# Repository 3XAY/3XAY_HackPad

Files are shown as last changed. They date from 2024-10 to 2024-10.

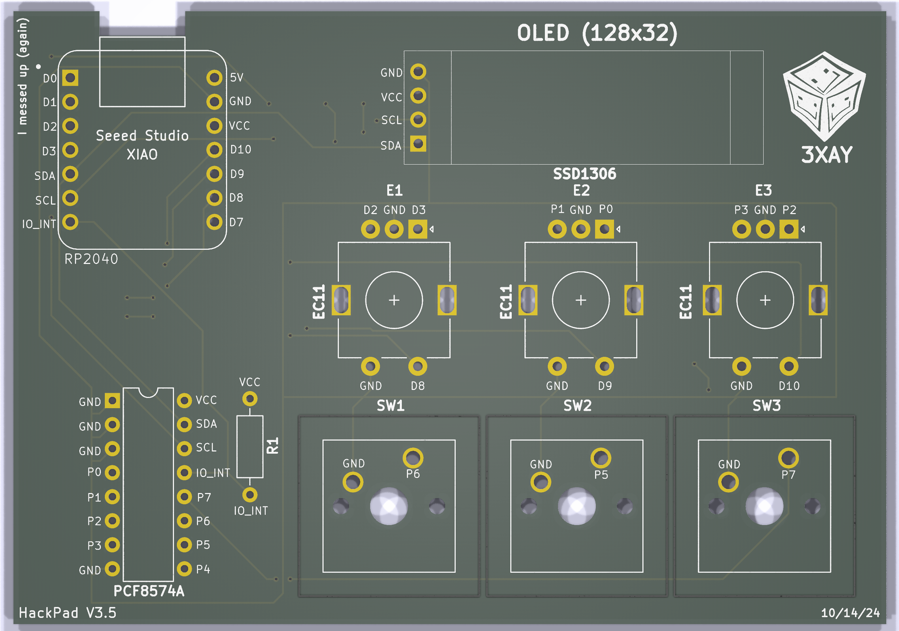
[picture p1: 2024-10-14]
Images/V3.5/PCB3DViewFront.png

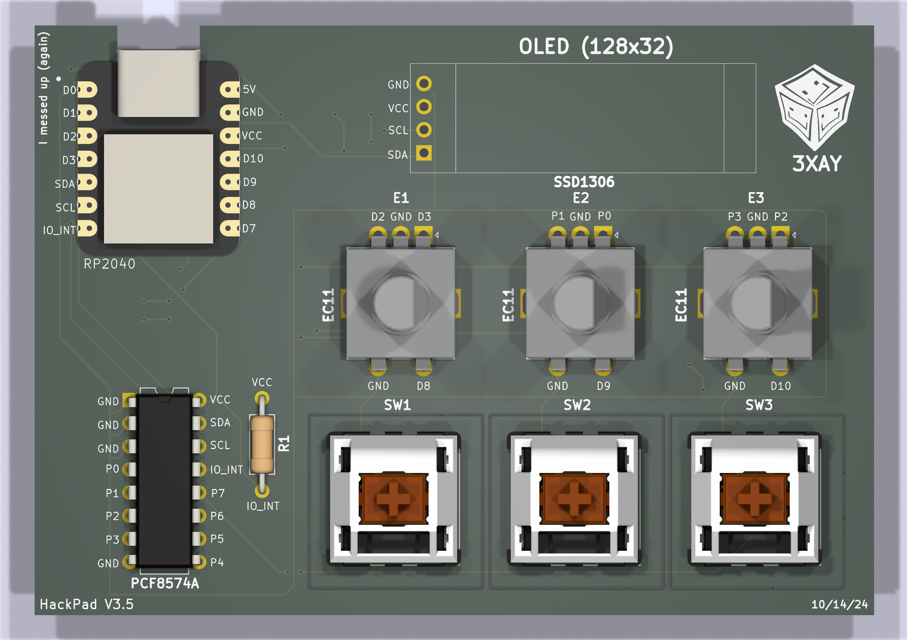
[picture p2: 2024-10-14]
Images/V3.5/PCB3DViewFrontWithModels.png

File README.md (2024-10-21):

# HackPad

This is currently a work in progress. **THIS MEANS NOTHING IS TESTED, DO NOT ATTEMPT TO USE THIS AS A GUIDE** (as of now)
[here's the submission link if you want it](https://github.com/hackclub/hackpad/pull/187)

This is my submission for Hack Club's HackPad YSWS (You ship we ship).
My progress will be throughouly documented here.

## Images
These are screenshots from the development process with each design iteration. (For the PCB / Case, code can be reviewed via the version history)

## KiCad
These are the KiCad files.

## Blender
Any Blender files made will be stored here, these are either sketches, renders, or CAD files
- Here's the tool I used to export from KiCad to Blender: https://github.com/30350n/pcb2blender

## Firmware
All of the firmware is written in Circuitpython (currently untested)

## YouTube Shorts Recaps
https://youtube.com/playlist?list=PL8pZ9v0F1Ks2gfHrP7J-pUTj4NAnL8gHc&si=MliIfDuidp5TVAae

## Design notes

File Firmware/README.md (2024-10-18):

The .UF2 file is meant to be flashed to the MCU (RP2040 in this case), allowing it to work with CircuitPython

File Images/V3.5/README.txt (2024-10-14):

The PCB schematic is the same as V3, so are the keymaps and the idea.

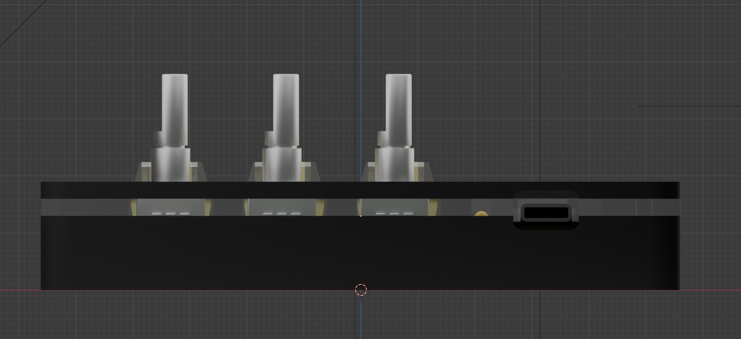
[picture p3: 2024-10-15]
Images/V3.5/unfinishedCaseUSBPort.png

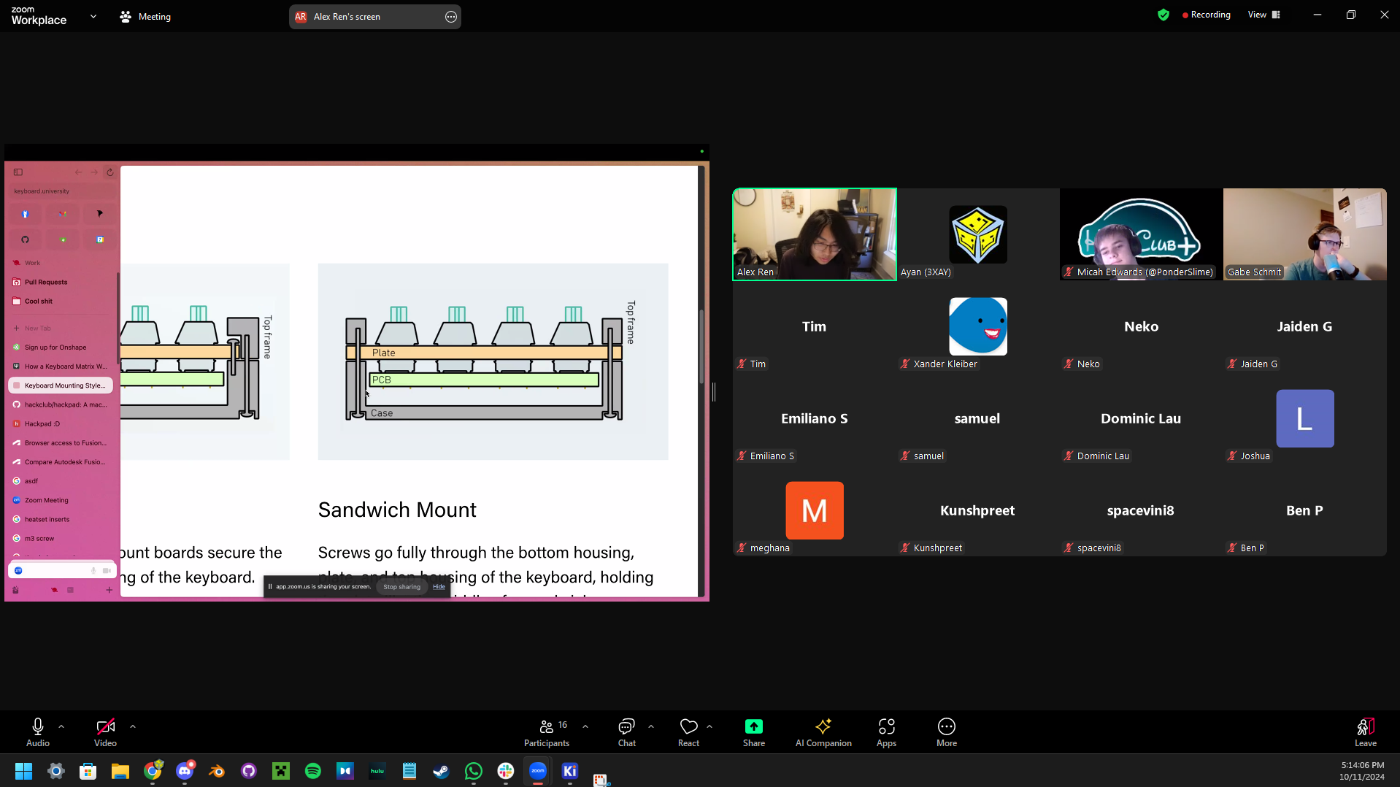
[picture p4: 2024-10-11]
Images/General/10-11-24 - Workshop.png

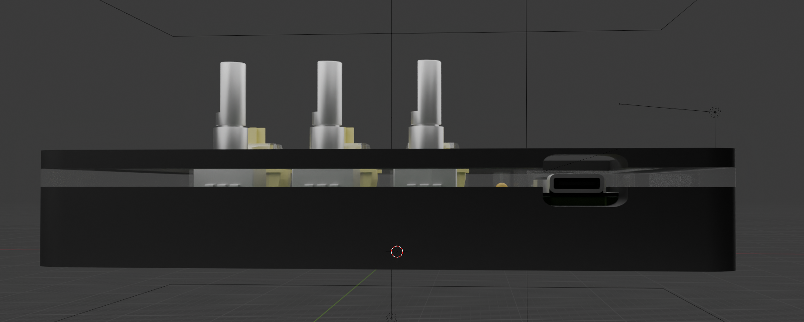
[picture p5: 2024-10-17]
Images/V3.5/finishedCaseUSBPort.png

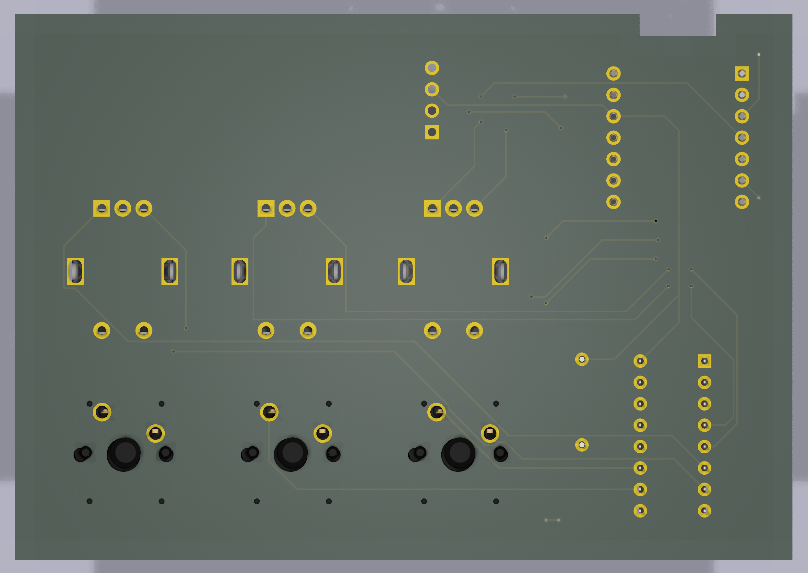
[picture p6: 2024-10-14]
Images/V3.5/PCB3DViewBackWithModels.png

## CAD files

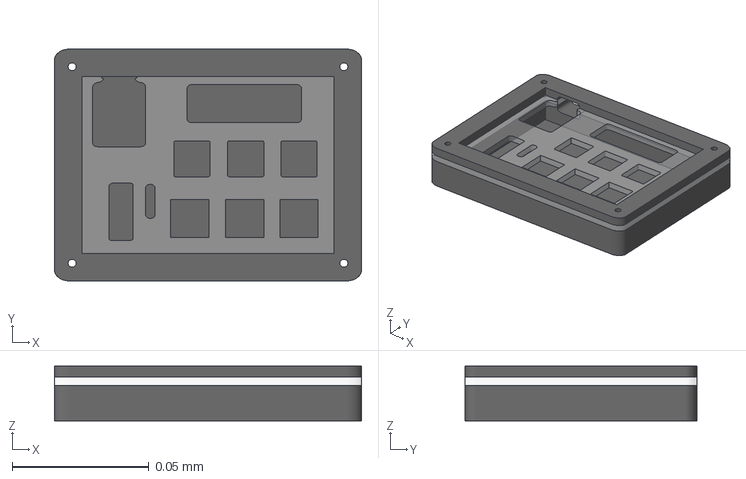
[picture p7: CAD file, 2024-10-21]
Blender/CAD Files/3MF/fullHackPad.3mf
0.112 x 0.0848 x 0.02 mm

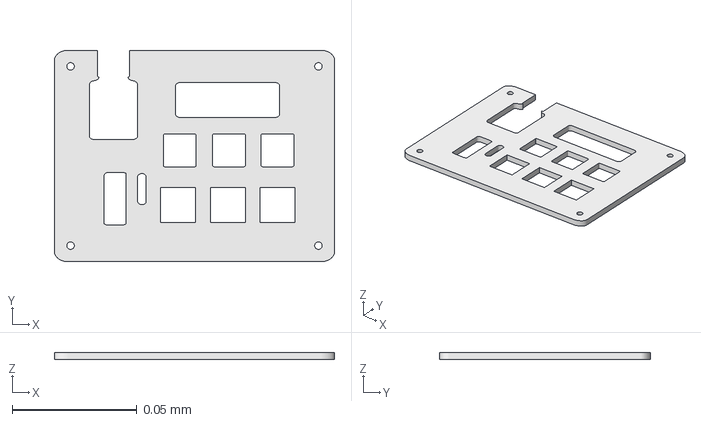
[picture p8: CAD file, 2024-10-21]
Blender/CAD Files/3MF/switchPlate.3mf
0.112 x 0.0848 x 0.003 mm

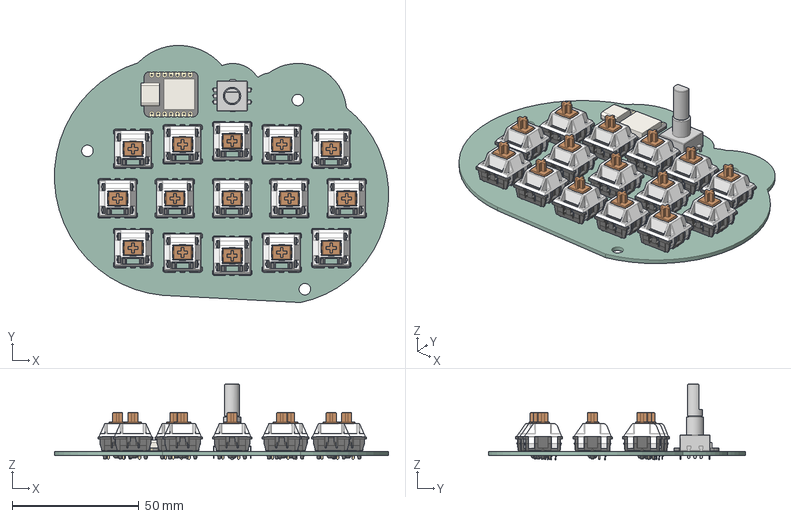
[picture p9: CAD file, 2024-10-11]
KiCad/footprints/models/models/frogpad.step
131.9 x 101.5 x 29.8 mm
SW_Cherry_MX_PCB x 15
Seeeduino Xiao v2
(Unsaved)
my_hackpad_PCB

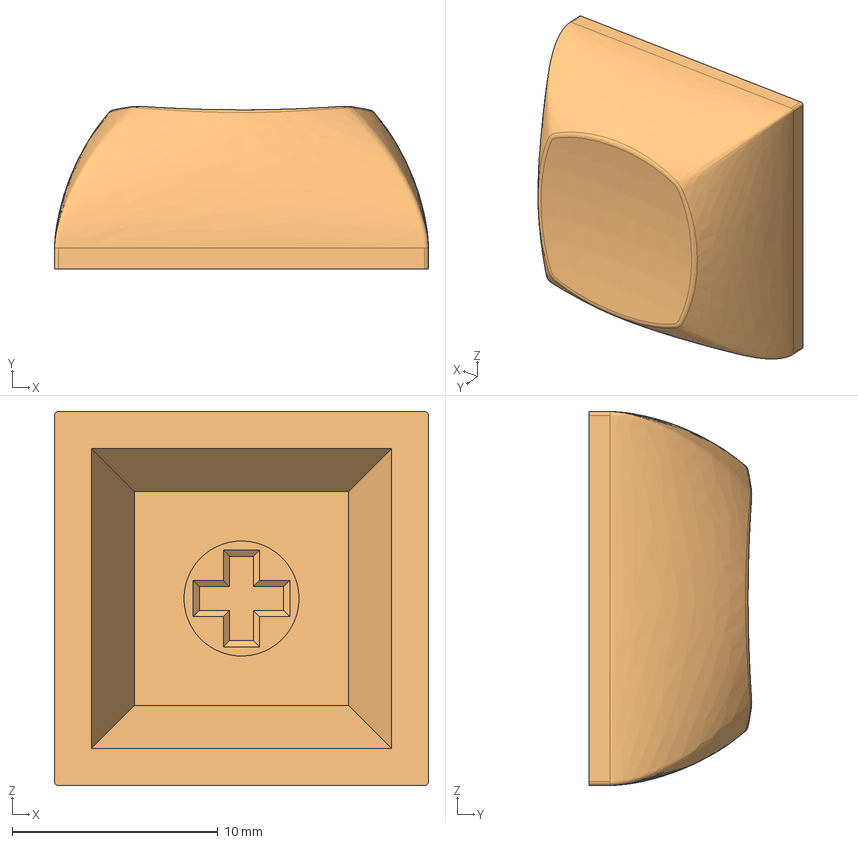
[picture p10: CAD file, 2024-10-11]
KiCad/footprints/models/models/DSA 1u.step
18.2 x 7.91 x 18.2 mm

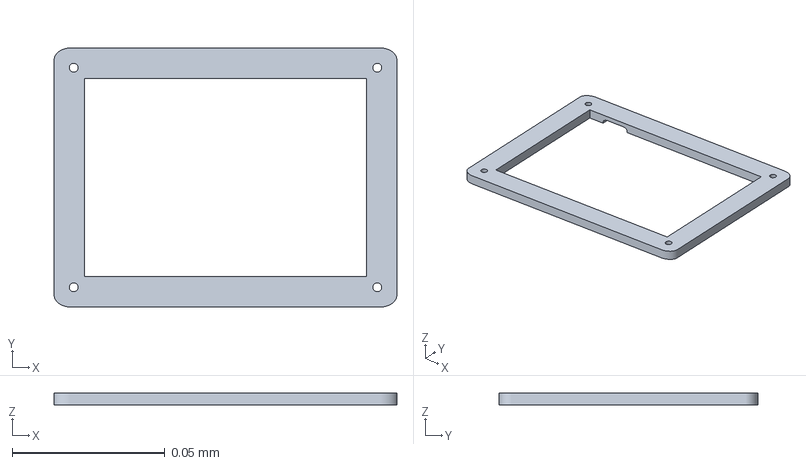
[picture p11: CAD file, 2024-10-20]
Blender/CAD Files/3MF/topPlate.3mf
0.112 x 0.0848 x 0.004 mm

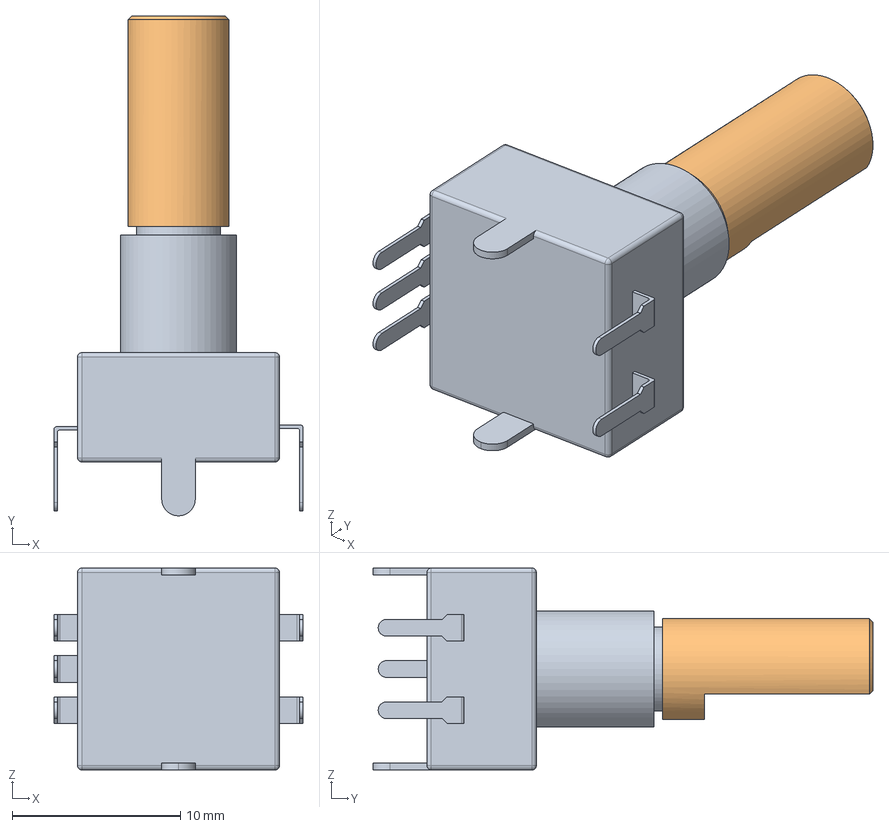
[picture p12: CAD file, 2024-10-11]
KiCad/footprints/models/models/Rotary Encoder.step
14.8 x 29.7 x 12.0 mm

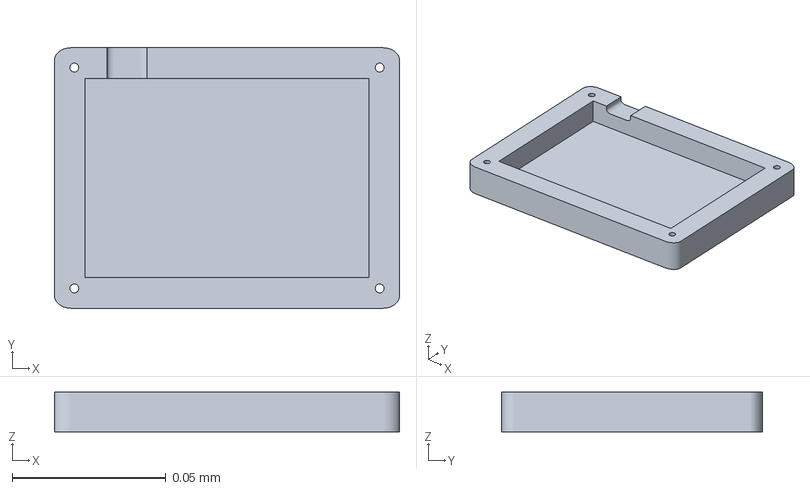
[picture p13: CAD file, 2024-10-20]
Blender/CAD Files/3MF/bottomCase.3mf
0.112 x 0.0848 x 0.013 mm

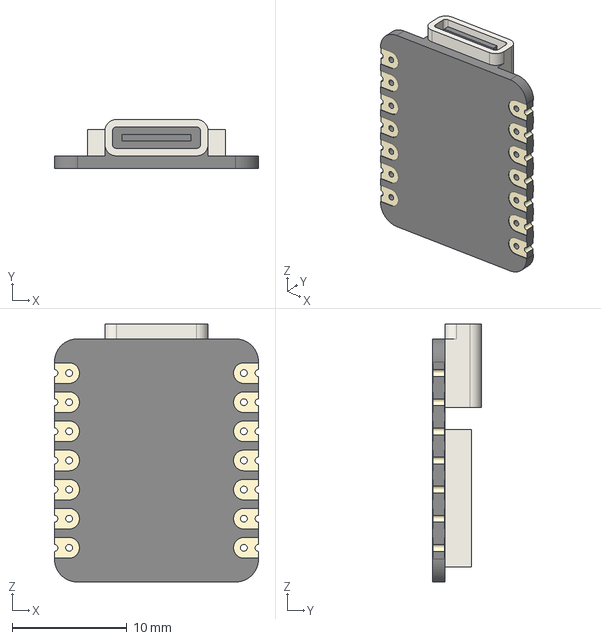
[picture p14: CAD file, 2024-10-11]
KiCad/footprints/models/models/Seeeduino_Xiao.step
17.8 x 4.27 x 22.5 mm

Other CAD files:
Blender/hackpadCAD.blend
Blender/hackpadIdea_V3.blend
hackpadIdea.blend

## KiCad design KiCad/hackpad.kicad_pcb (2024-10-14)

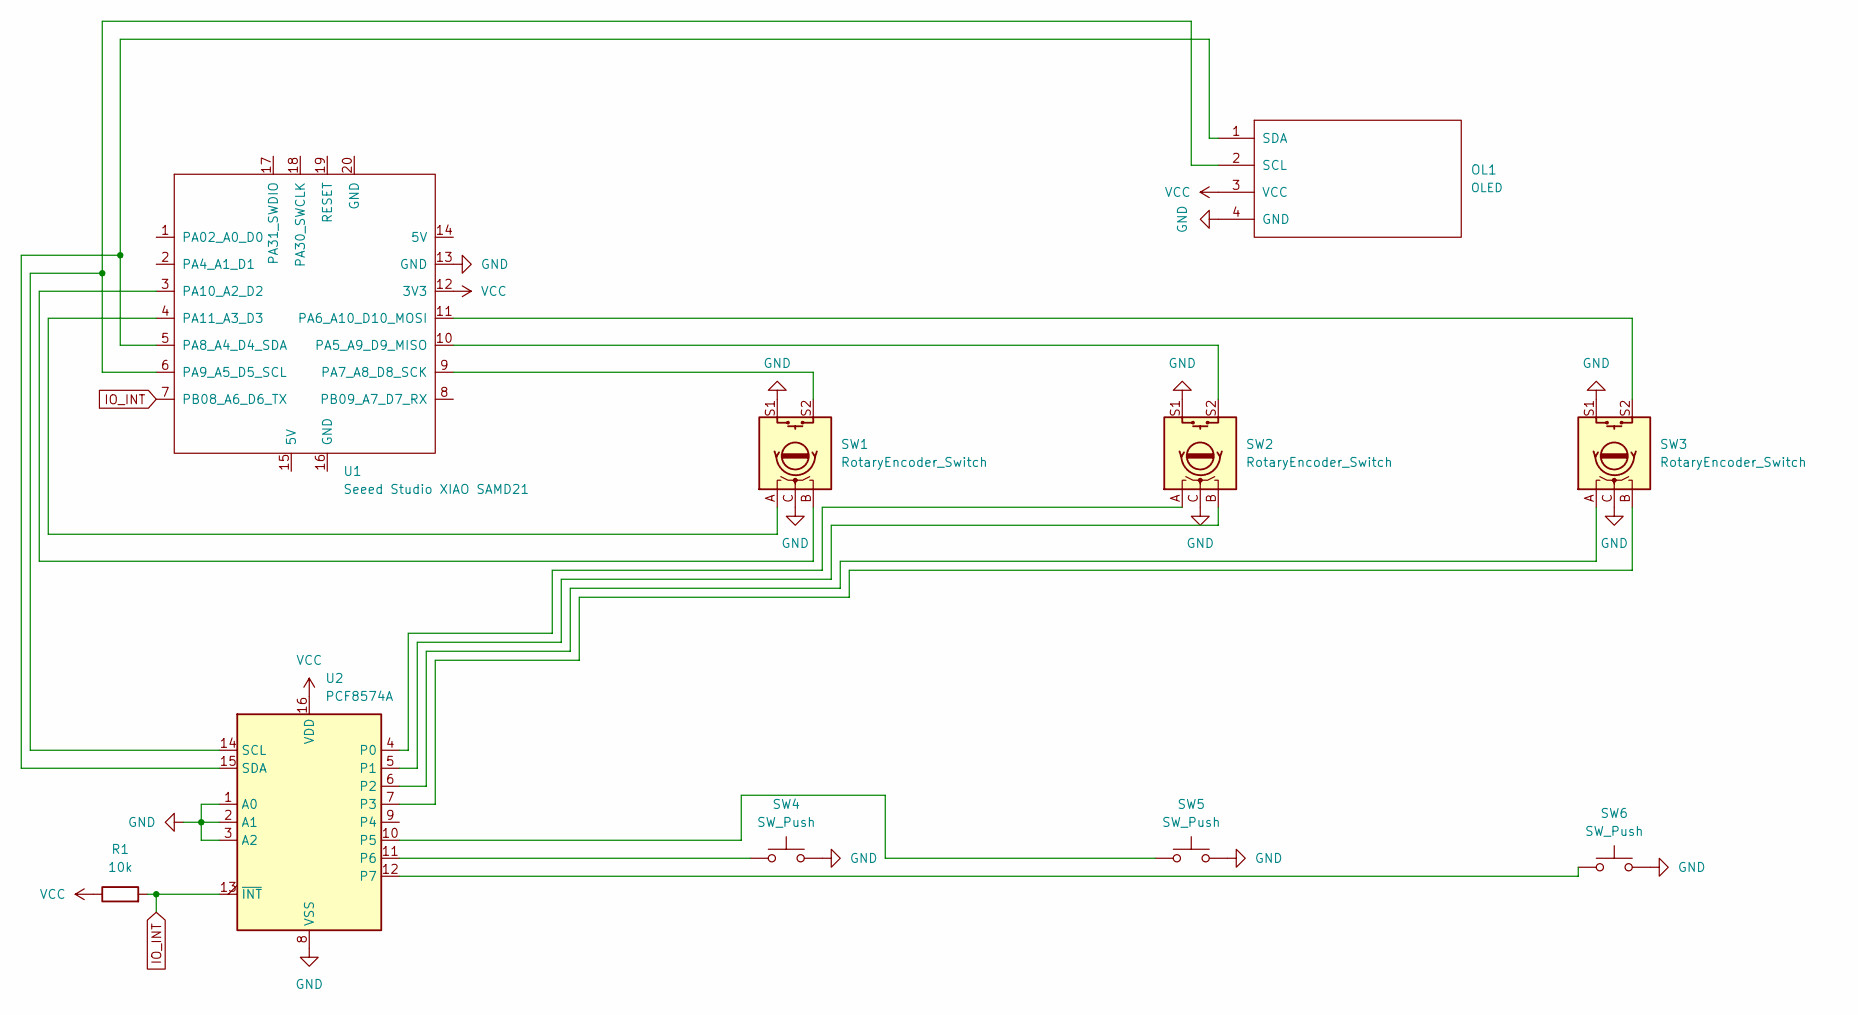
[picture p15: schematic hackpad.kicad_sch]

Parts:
OL1: OLED; SSD1306-0.91-OLED-4pin-128x32
R1: 10k; R_Axial_DIN0207_L6.3mm_D2.5mm_P10.16mm_Horizontal
SW1, SW2, SW3: RotaryEncoder_Switch; RotaryEncoder_Alps_EC11E-Switch_Vertical_H20mm
SW4, SW5, SW6: SW_Push; SW_Cherry_MX_1.00u_PCB
U1: Seeed Studio XIAO SAMD21; XIAO-Generic-Thruhole-14P-2.54-21X17.8MM
U2: PCF8574A; DIP-16_W7.62mm

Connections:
GND: OL1.4 (GND), SW1.C, SW1.S1, SW2.C, SW2.S1, SW3.C, SW3.S1, SW4.2, SW5.2, SW6.2, U1.13 (GND), U2.1 (A0), U2.2 (A1), U2.3 (A2), U2.8 (VSS)
IO_INT: R1.2, U1.7 (PB08_A6_D6_TX), U2.13 (~INT)
unnamed: OL1.2 (SCL), U1.6 (PA9_A5_D5_SCL), U2.14 (SCL)
unnamed: OL1.1 (SDA), U1.5 (PA8_A4_D4_SDA), U2.15 (SDA)
unnamed: SW2.S2, U1.10 (PA5_A9_D9_MISO)
unnamed: SW3.S2, U1.11 (PA6_A10_D10_MOSI)
unnamed: SW1.S2, U1.9 (PA7_A8_D8_SCK)
unnamed: SW1.B, U1.3 (PA10_A2_D2)
unnamed: SW1.A, U1.4 (PA11_A3_D3)
unnamed: SW2.A, U2.4 (P0)
unnamed: SW2.B, U2.5 (P1)
unnamed: SW3.A, U2.6 (P2)
unnamed: SW3.B, U2.7 (P3)
unnamed: SW5.1, U2.10 (P5)
unnamed: SW4.1, U2.11 (P6)
unnamed: SW6.1, U2.12 (P7)
VCC: OL1.3 (VCC), R1.1, U1.12 (3V3), U2.16 (VDD)

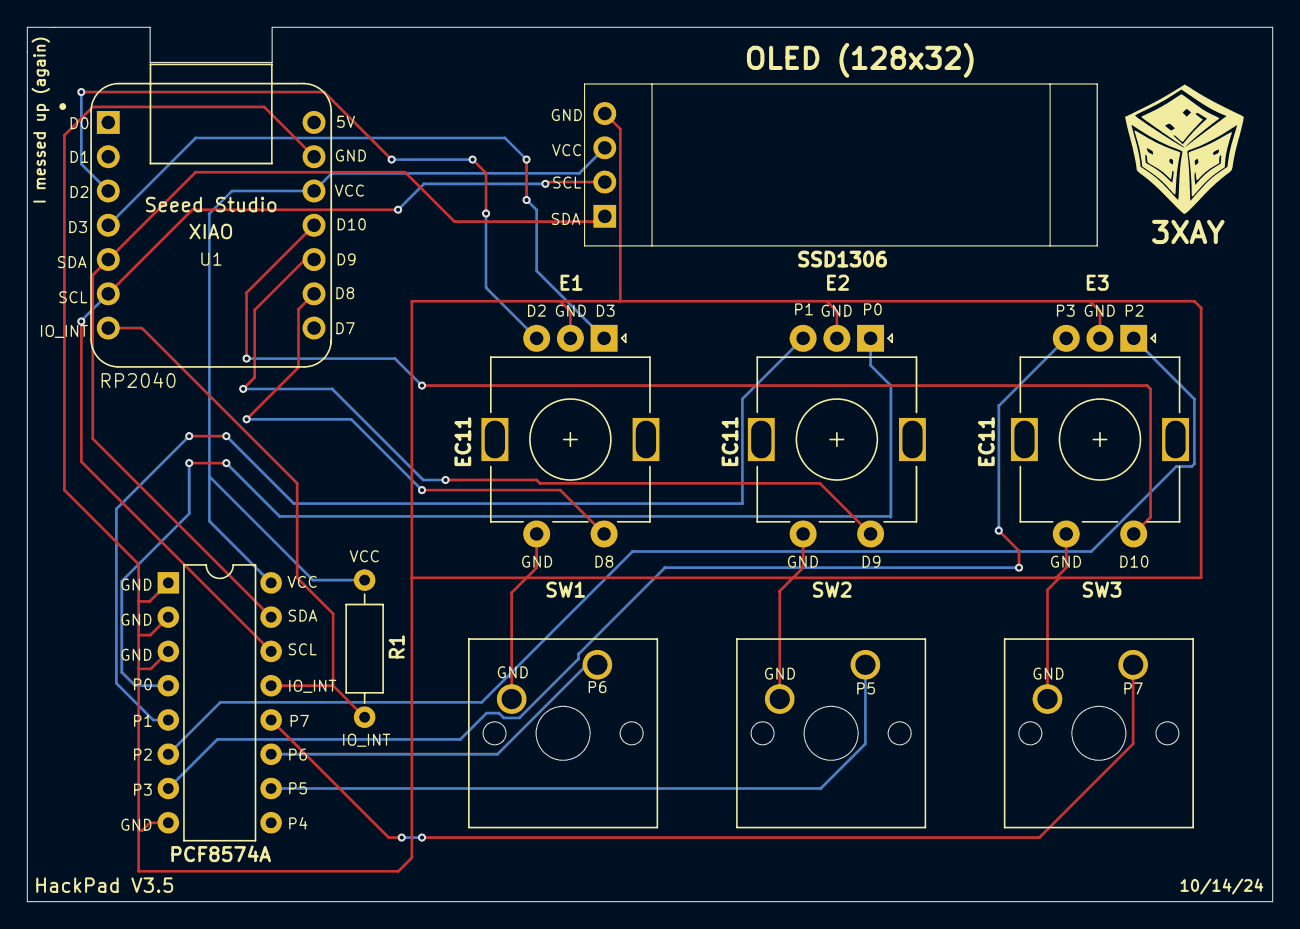
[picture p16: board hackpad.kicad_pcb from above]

Board: 2 copper layers, 92.3 x 64.8 mm, 10 parts (0 on the bottom side), 17 nets.

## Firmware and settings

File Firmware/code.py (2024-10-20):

import board #Allows for access to the board's systems
from digitalio import DigitalInOut, Direction, Pull #Allows for digital I/O access
import adafruit_pcf8547 #I/O expander library
from adafruit_debouncer import Button #Button presses
import usb_hid #USB Devices
from adafruit_hid.mouse import Mouse #Mouse clicks / wheel
from adafruit_hid.keyboard import Keyboard #Keyboard presses
from adafruit_hid.keycode import Keycode #Key press names
from adafruit_hid.consumer_control import ConsumerControl #Media presses
from adafruit_hid.consumer_control_code import ConsumerControlCode #Media press codes
import rotaryio #For encoder
import busio #For i2c access
import adafruit_ssd1306 #Display lib for ssd1306


i2c = board.I2C() #i2c object from the SDA/SCL pins

pcf = adafruit_pcf8547.PCF8574(i2c, 0x20) #Save the IO expander as an object with an address of 0x20 (all address pins to ground)

i2cPins = busio.I2C(board.SCL, board.SDA) #Get the I2C pins for OLED
oled = adafruit_ssd1306.SSD1306_I2C(128, 32, i2cPins) #Creates an OLED object with a 128x32 resolution

#Get pins from PCF
p6 = pcf.get_pin(6) #Gets a DigitalInOut pin
p5 = pcf.get_pin(5)
p7 = pcf.get_pin(7)

#Get EC11 pins from PCF
p0 = pcf.get_pin(0)
p1 = pcf.get_pin(1)
p2 = pcf.get_pin(2)
p3 = pcf.get_pin(3)

#Get EC11 R1 pins and S1-3 pins from board
a3 = DigitalInOut(board.A3)
a2 = DigitalInOut(board.A2)
a8 = DigitalInOut(board.A8)
a9 = DigitalInOut(board.A9)
a10 = DigitalInOut(board.A10)

#Setup pins
a8.direction = Direction.INPUT
a8.pull = Pull.UP
a9.direction = Direction.INPUT
a9.pull = Pull.UP
a10.direction = Direction.INPUT
a10.pull = Pull.UP
p6.direction = Direction.INPUT
p6.pull = Pull.UP
p5.direction = Direction.INPUT
p5.pull = Pull.UP
p7.direction = Direction.INPUT
p7.pull = Pull.UP
a3.direction = Direction.INPUT
a2.direction = Direction.INPUT
p0.direction = Direction.INPUT
p1.direction = Direction.INPUT
p2.direction = Direction.INPUT
p3.direction = Direction.INPUT

#Create switches with their pin, a keypress duration of 175ms, a hold duration of 350ms, and outputs True when pressed
sw1 = Button(a8, 175, 350, True)
sw2 = Button(a9, 175, 350, True)
sw3 = Button(a10, 175, 350, True)
sw4 = Button(p6, 175, 350, True)
sw5 = Button(p5, 175, 350, True)
sw6 = Button(p7, 175, 350, True)

#Create encoders with their pins
e1 = rotaryio.IncrementalEncoder(a3, a2)
e2 = rotaryio.IncrementalEncoder(p0, p1)
e3 = rotaryio.IncrementalEncoder(p2, p3)

#Create last_pos objects
last_pos1 = 0
last_pos2 = 0
last_pos3 = 0

#Create mouse object
mouse = Mouse(usb_hid.devices)

#Create keyboard object
kbd = Keyboard(usb_hid.devices)

#Create media object
media = ConsumerControl(usb_hid.devices)

while True: #Main loop
    #Update switch state
    sw1.update()
    sw2.update()
    sw3.update()
    sw4.update()
    sw5.update()
    sw6.update()

    #OLED refresh
    oled.fill(0) #Clear screen
    oled.text("Test text", 0, 0) #Writes "test text" at (0,0)
    oled.text("Switch 6 state: " + sw6.pressed, 0, 20) #Shows the state of SW6 at (0,20)
    oled.show() #Update the display

    #Switch outputs
    if sw1.pressed:
        kbd.send(Keycode.SPACEBAR) #Play/pause

    if sw2.pressed:
        kbd.send(Keycode.F) #Fullscreen in Davinci

    if sw3.pressed:
        kbd.send(Keycode.CTRL, Keycode.S) #Save

    if sw4.pressed:
        kbd.send(Keycode.M) #Marker in Davinci

    if sw5.pressed:
        kbd.send(Keycode.CTRL, Keycode.BACKSLASH) #Split clip in Davinci

    if sw6.pressed:
        kbd.send(Keycode.ALT, Keycode.BACKSLASH) #Join clip in Davinci

    #Encoder stuff
    pos1 = e1.position
    pos2 = e2.position
    pos3 = e3.position

    if last_pos1 != pos1:
        if last_pos1 > pos1:
            media.send(ConsumerControlCode.VOLUME_DECREMENT) #Counter-clockwise
        else:
            media.send(ConsumerControlCode.VOLUME_INCREMENT) #Clockwise

    if last_pos2 != pos2:
        if last_pos1 > pos1:
            media.send(ConsumerControlCode.SCAN_PREVIOUS_TRACK) #Placeholder, supposed to be horizontal scroll
        else:
            media.send(ConsumerControlCode.SCAN_NEXT_TRACK)
            
    if last_pos3 != pos3:
        if last_pos1 > pos1:
            kbd.send(Keycode.CTRL, Keycode.EQUALS)
        else:
            kbd.send(Keycode.CTRL, Keycode.MINUS)

    #Reset last position var
    last_pos1 = pos1
    last_pos2 = pos2
    last_pos3 = pos3

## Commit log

2024-10-10 Upload KiCad Files
    [hackpad.kicad_pcb, hackpad.kicad_sch]
2024-10-10 Update and rename hackpad.kicad_pcb to KiCad/hackpad.kicad_pcb
    [hackpad.kicad_pcb]
2024-10-10 Update and rename hackpad.kicad_sch to KiCad/hackpad.kicad_sch
    [hackpad.kicad_sch]
2024-10-10 Added blend files
    [hackpadIdea.blend]
2024-10-11 HackPad Day 4 KiCad Files
    [hackpad.kicad_pcb, hackpad.kicad_sch]
2024-10-11 Remaining KiCad libraries
2024-10-11 Delete KiCad/footprints/empty.txt
    This was only used to make the "footprints" folder
2024-10-11 Models by PonderSlime
    [DSA 1u.step, Rotary Encoder.step, Seeeduino_Xiao.step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]
2024-10-11 PCB images with models provided by PonderSlime
2024-10-13 Updated Blender files
    [hackpadIdea.blend]
2024-10-14 Add PCB V3.5 Images
2024-10-14 PCB V3.5 KiCad Files Update
    [hackpad.kicad_pcb, hackpad.kicad_sch]
2024-10-14 Official HackPad OLED Footprint (PCB V3.5)
2024-10-14 PCB V3.5 to Blender file (PCB2Blender output)
2024-10-15 Added unfinished case CAD images (V3.5)
2024-10-15 Update CAD (V3.5)
2024-10-17 Upload case (V3.5) files in OBJ and 3MF
    [case.3mf, switchPlate.3mf, topPlate.3mf]
2024-10-17 Add finished case (V3.5) images from top and USB
2024-10-17 Upload finished blend file for case (V3.5)
2024-10-20 Finished firmware (V0.1)
    This firmware should have basic functionality for Davinci Resolve
    There are also some files for the codeWithCustomLibs.py file, this is a test. It is not designed to be ran.
    [code.py, codeWithCustomLibs.py]
2024-10-20 Fixed errors
    - Acrylic switch plate now has 3mm holes, but 3d printed parts still have 2.9mm
    - Made top plate 1mm taller to accommodate 20mm M3 screws
    - Flattened the switch plate (was slightly curved before, which would be HORRIBLE for CNCing the plate)
2024-10-20 Fixed errors
    - Reuploaded exported files with errors fixed
    - Read the rules and also uploaded all of the parts in one file for each format
    [bottomCase.3mf, fullHackPad.3mf, switchPlate.3mf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]
2024-10-21 Fixed switch plate errors
    Resistor hole was plugged
    Key switch holes were too loose
2024-10-21 Re-upload fixed CAD files
    - Fixed resistor hole being plugged
    - Fixed switch plate hole sizing
    [bottomCase.3mf, fullHackPad.3mf, switchPlate.3mf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]
